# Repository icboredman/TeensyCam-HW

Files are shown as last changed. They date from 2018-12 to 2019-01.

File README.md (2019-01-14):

# TeensyCam-HW
Hardware design of TeensyCam - a stereo camera module based on MT9V034 sensor and Teensy3.6 microcontroller board.

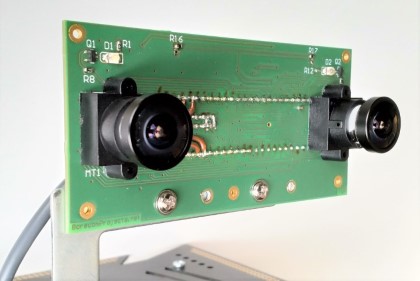
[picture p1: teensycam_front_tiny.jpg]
TeensyCam stereo camera module


#### _Status:_
* mature (more-or-less)

## Features:
* Created using [Altium Designer](https://www.altium.com/altium-designer/) software suite
* Main components: two MT9V034 imaging sensors + [Teensy 3.6](https://www.pjrc.com/store/teensy36.html) microcontroller board
* Hardware synchronized simultaneous image capture
* Stereo baseline: 8 cm
* Resolution: 720 x 480 (vertical can be reduced to save bandwidth)
* Image format: raw, uncompressed, 10 bits per dot (monochrome)
* Interface: single USB 2.0 high speed port, CDC device profile
* Power: through USB, 150 mA
* Horizontal field of view: 105°
* Speed: 30 FPS max (configurable)
* Exposure control: pre-set or automatic
* Analog gain control: pre-set or automatic
* Compounding mode control
* Configurable number of lines to send to host

Module schematics diagram: [PDF](https://github.com/icboredman/TeensyCam-HW/blob/master/Project%20Outputs%20for%20Camera/Printouts/Schematic%20Prints.PDF)

Teensy3.6 USB high speed device mode connetion diagram: [PNG](https://github.com/icboredman/TeensyCam-HW/blob/master/Schematic36_USBHS.png)

---
### Firmware
MCUXpresso-based embedded software project: https://github.com/icboredman/TeensyCam-SW

### Software
ROS node running on host computer: https://github.com/icboredman/camera_node

---
More info in my blog page: https://BoredomProjects.net/index.php/projects/robot-navigation-using-stereo-vision-part-2

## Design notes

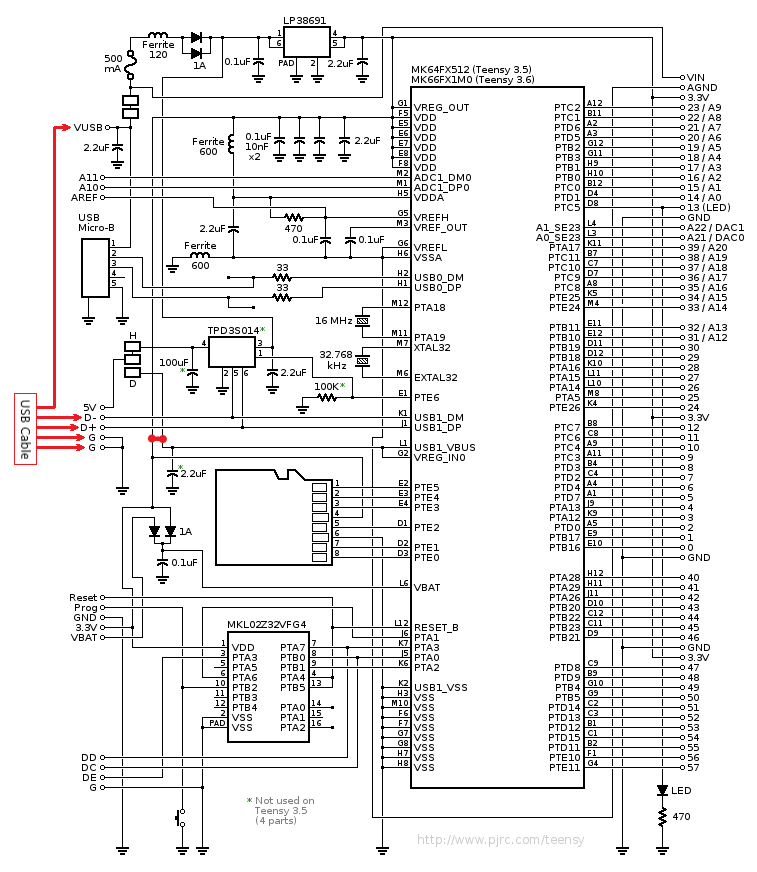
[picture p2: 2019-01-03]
Schematic36_USBHS.png

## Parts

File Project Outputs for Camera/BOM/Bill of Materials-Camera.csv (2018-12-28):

Comment | Description | Designator | Footprint | LibRef | Quantity
0.1u | Capacitor (Semiconductor SIM Model) | C1, C2, C3, C4, C5, C7, C8, C9, C10, C11, C12, C14, C15, C17, C18, C20 | 1608[0603] | Cap Semi | 16
10uF | Polarized Capacitor (Surface Mount) | C16, C19, C21 | C1206 | Cap Pol3 | 3
NP | Capacitor (Semiconductor SIM Model) | C22 | 1608[0603] | Cap Semi | 1
LED | Typical RED, GREEN, YELLOW, AMBER GaAs LED | D1, D2 | 3.2X1.6X1.1 | LED2 | 2
Bead | Inductor | L1, L2 | INDC1608L | Inductor | 2
NP | Inductor | L3 | INDC3216 | Inductor | 1
CCD | CCD | Lens1, Lens2 | CCD_LENS_20MM | lensCCD_20 | 2
MT9V034 | CMOS | MT1, MT2 | CLCC_48 | MT9V034 | 2
NPN | NPN Bipolar Transistor | Q1, Q2 | SOT23_N | NPN | 2
330 | Resistor | R1, R12 | J1-0603 | Res1 | 2
1K5 | Resistor | R2, R3, R4, R5, R6, R7 | J1-0603 | Res1 | 6
4K7 | Resistor | R8, R14 | J1-0603 | Res1 | 2
12K | Resistor | R9, R15 | J1-0603 | Res1 | 2
0R | Resistor | R10, R11 | 0402 | Res1 | 2
NP | Resistor | R13, R18, R19 | 0402 | Res1 | 3
NP | Resistor | R16, R17 | J1-0603 | Res1 | 2
Teensy3_6 |  | U1 | Teensy3.6-most-pins | Teensy3_6 | 1
TPS79333 | 200-mA Low-Dropout Linear Regulator | U2, U3 | SOT23-5_L | TPS79333 | 2
NP | 1.5MHz SYNCHRONOUS STEP-DOWN DC-DC CONVERTER | U4 | SOT23-5_L | AP3417C | 1

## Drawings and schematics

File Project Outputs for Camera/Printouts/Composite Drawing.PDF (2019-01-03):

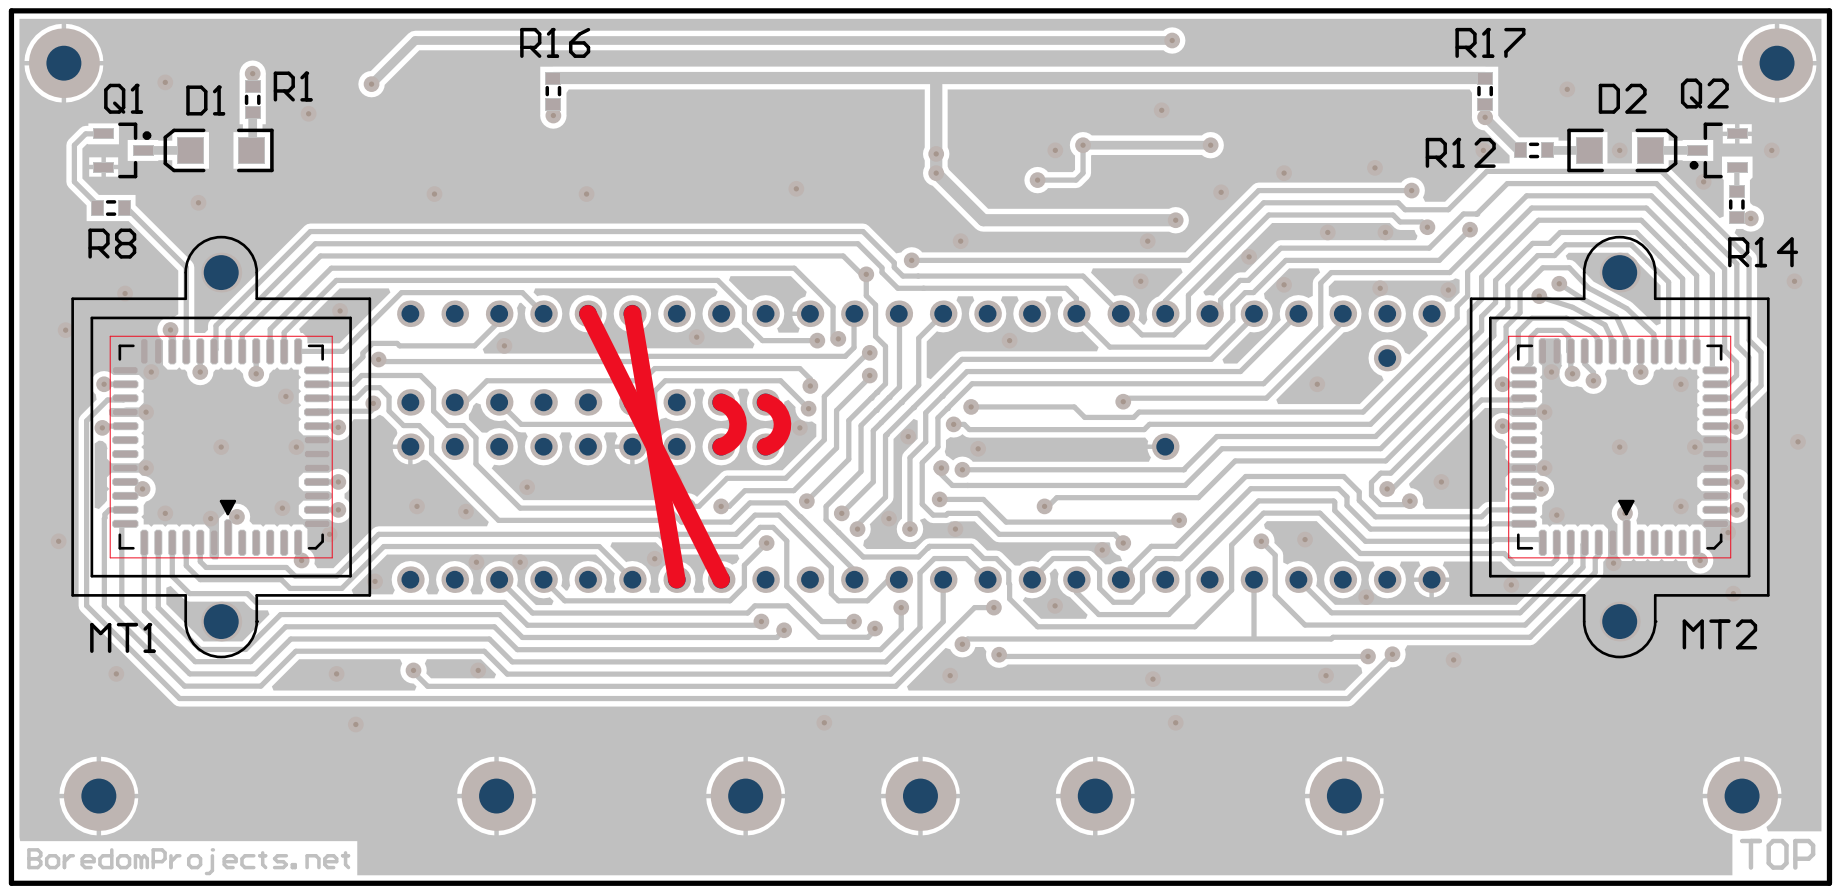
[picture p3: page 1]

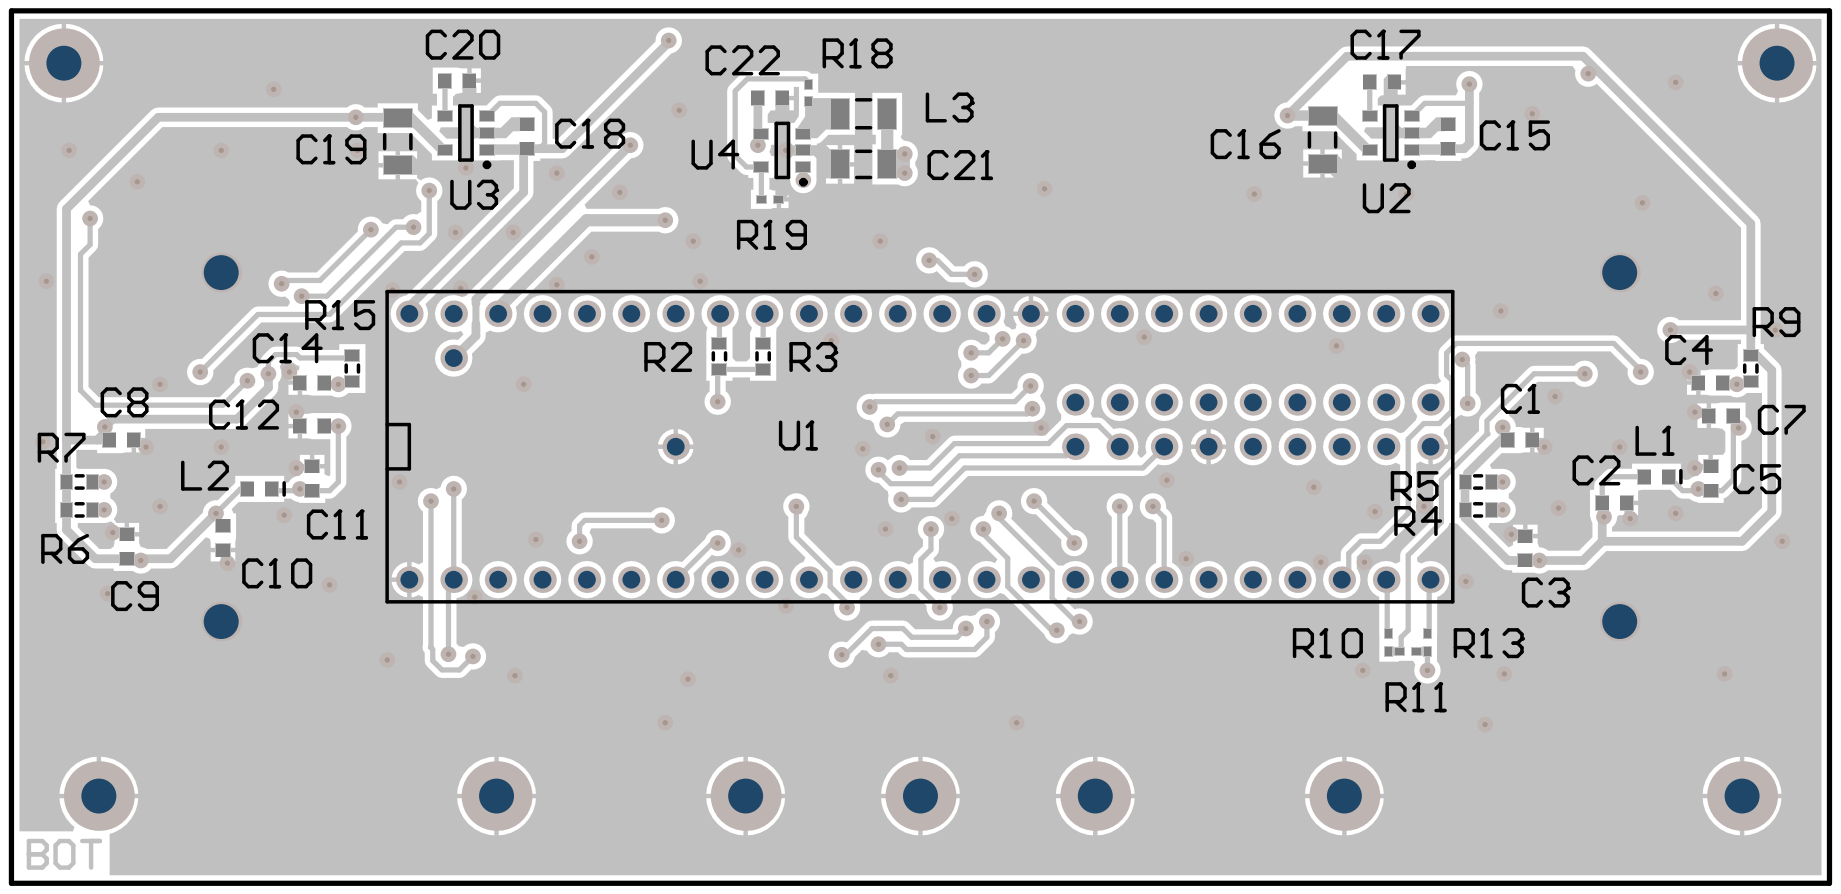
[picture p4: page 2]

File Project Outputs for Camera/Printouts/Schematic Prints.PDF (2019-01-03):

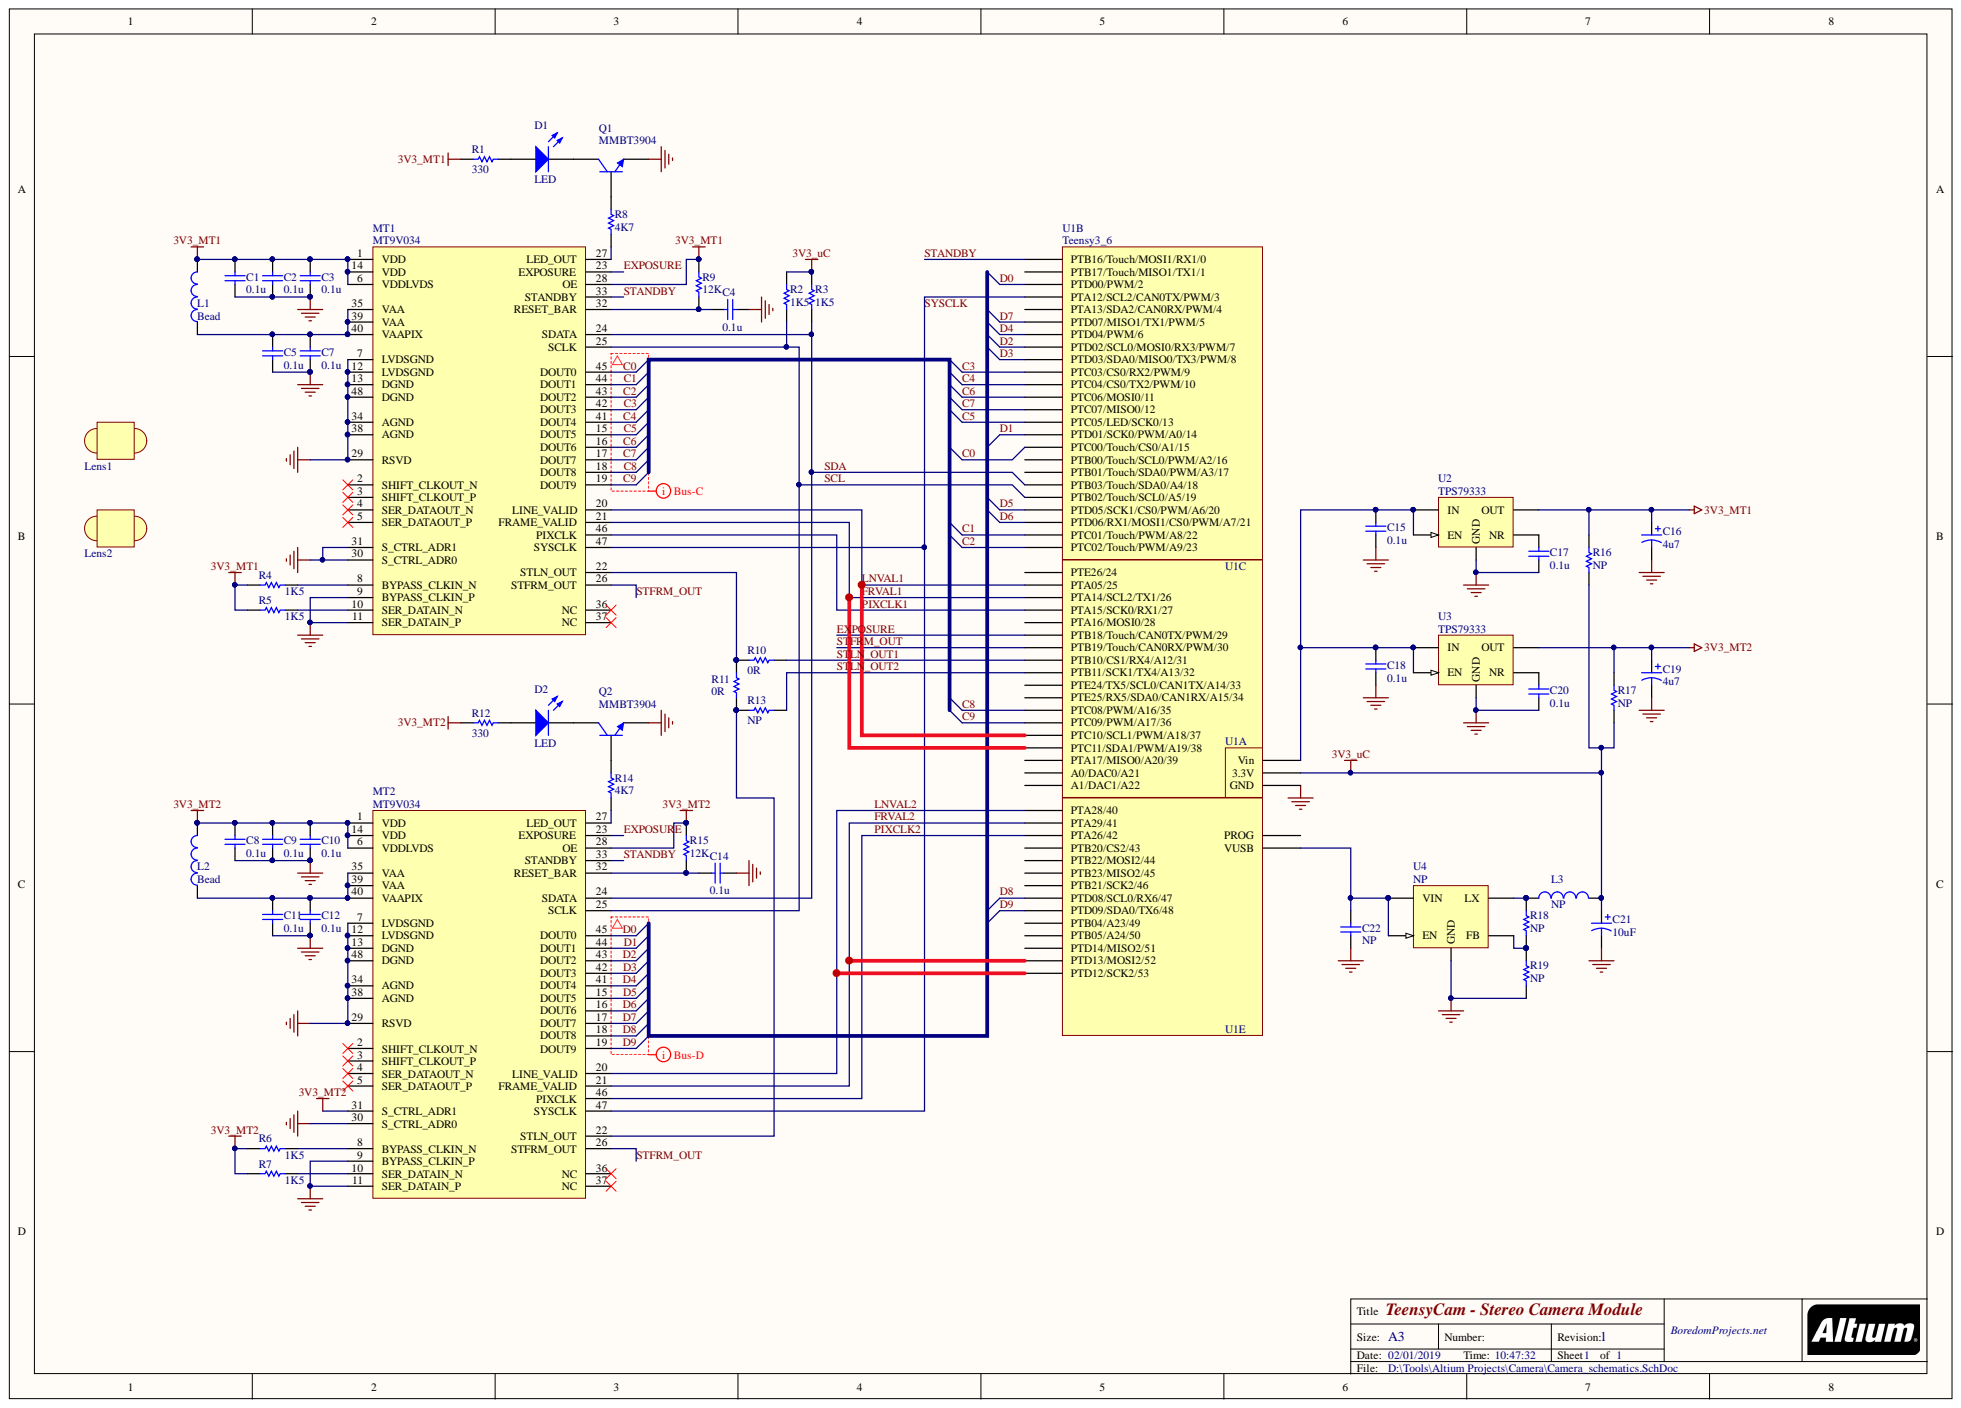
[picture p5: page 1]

1 1 | | E XPOSU STFR ST | L | R E M_O U T N_O U T 1

Te e n syCam -S te r eo Cam e ra Modu le Ti t l e | Boredom P roject s.net

Size: A 3 | Number : | Revi s ion: 1
Date: Ti me: | | Sheet 1 of 1

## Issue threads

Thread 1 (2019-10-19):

Have you considered upgrading to the Teensy 4.0?

chutsu, 2019-10-19:
Hi,

Really like your project and thanks for sharing. I noticed you had some trouble with regards to the High-Speed USB device mode. The Teensy 4.0 seems to be quite an improvement over the 3.6. Namely:

- ARM Cortex-M7 at 600 MHz
- 2 USB ports, both 480 MBit/sec

Or were you having more of a software issue where the Arduino drivers Teensy provided does not support High-Speed USB?

Source: https://www.pjrc.com/store/teensy40.html

icboredman, 2019-10-20:
Thanks for your interest!
Yes, the problem with Arduino for Teensy 3.6 (teensyduino) was the lack of high-speed USB support. That's why I switched to MCUXpresso.
Teensy 4.0 looks very nice! If only it was around a year ago when I started this development!
Although, bit-banging two MT9V034 sensors at the same time requires a lot of pins and 4.0 seems to have fewer GPIOs than 3.6. Still, I'm going to take a closer look on it.
Thanks.

chutsu, 2019-10-20:
If you could point me to the right direction / show me some notes in bit-banging the MT9V034 that would be awesome. I'm considering doing a very similar stereo rig to yours so we could potentialy compare notes.

Btw if you need stereo calibration I have coded that up in my [`proto`](https://github.com/chutsu/proto) project. See launch file [here](https://github.com/chutsu/proto/blob/master/proto_ros/launch/calib_stereo.launch) and configuration file [here](https://github.com/chutsu/proto/blob/master/proto_ros/config/calib_intel_d435i.yaml).

Compared to other tool boxes:
- The installation of my code base is trivial, I've written scripts to automate that and I have a [CI to prove it](https://github.com/chutsu/proto/actions).
- Simiar to [Kalibr](https://github.com/ethz-asl/kalibr) I use an AprilGrid, but without the installation headaches of Kalibr.
- Super fast see [example video ](https://www.youtube.com/watch?v=mvisjwUpngg), granted the video does not show the pre-processing step, but as you can see the actual optimization is rather short (this is around 1400 pictures x 2 cams, OpenCV takes around 5-10 minutes on 100 pictures alone).

icboredman, 2019-10-22:
Basically, for each MT9 module, one would need a I2C interface, 10 pins of data IO and 8 control IO pins.
Take a look at [TeensyCam.c](https://github.com/icboredman/TeensyCam-SW/blob/master/sources/TeensyCam.c), specifically at functions [TakeSnapshot](https://github.com/icboredman/TeensyCam-SW/blob/a7d9e8f0e8e7e943189e58bfd0f1a95039f90173/sources/TeensyCam.c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) and [ReadCameraLine](https://github.com/icboredman/TeensyCam-SW/blob/a7d9e8f0e8e7e943189e58bfd0f1a95039f90173/sources/TeensyCam.c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).

So far, I have used [fisheye-stereo-calibration](https://github.com/icboredman/fisheye-stereo-calibration) repository based on OpenCV functions, but I will take a look at your tools. Thanks for the info!

Closed 2019-10-23.

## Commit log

2018-12-28 added missing files
    [Bill of Materials-Camera.csv, Camera.PrjPCB, Camera_pcb.PcbDoc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]
2019-01-03 Updated README, updated drawings, added missing files
    [Camera_pcb.PcbDoc, Camera_schematics.SchDoc]
